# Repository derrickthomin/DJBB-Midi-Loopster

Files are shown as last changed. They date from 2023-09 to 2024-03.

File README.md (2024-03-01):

# DJBB-Midi-Loopster

The Midi Loopster is a MIDI 4x4 drum pad and midi looper based on the Raspberry Pi Pico.



Demo:          https://www.youtube.com/watch?v=YDxO62Sy1Qc&lc=UgxtoEvjVZX9zsOcOUB4AaABAg

Build Video:   https://youtu.be/qznFqSrzPKM

## Background
I created the [DJBB Arcade Button MIDI Drumpad](https://github.com/derrickthomin/djbb-midi-box) as an experiment on how to use a Raspberry Pi Pico microcontroller as a Midi controller.

It worked pretty well but I honestly don't like the super loud arcade buttons so I never really used it. I wanted an excuse to try designing my first PCB, so I decided to go for a version two of my original design except with these changes:

- Use Cherry style key switches for the buttons (quieter but still feel nice. Also smaller)

- Uses a custom PCB for max compactness and ease of build

- Switch out controls for a function button and encoder

- Firmware re-write

## Components
[DigiKey List with most parts](https://www.digikey.com/en/mylists/list/QX3GPIZNYA)

Also see BOM csv in this repo

1 x DJBB Midi Loopster PCB

1 x Raspberry Pi Pico or Pico W With Headers **djt depends on wifi stuff

1 x SSD1306 OLED Screen

5 x 10k Resistors

1 x 10 Ohm Resistor

1 x 33 Ohm Resistor

17 x Cherry MX Style key switches

1 x Rotary Encoder 

1 x 3.5mm Audio Jack

3 x 10nF Capacitors

17 x Cherry style keycaps (technically optional... but you want em)

1 x 3D printed case (optional)

1 x 3D printed screen case (optional)

1 x 4 pin female large headers for screen (optional)

4 x m2.5 screws - for screen case (optional) 

4 x m3 screws - for case (optional)

Models for printed parts here:
https://www.printables.com/model/661953-djbb-midi-loopster-3d-printed-parts

## Assembly
See the detailed Loopster Manual and Assembly Guide pdf in this repo for in depth assembly instructions.

In short:
- Solder the fn button and top left pad to the front of the board. You must do this first!! These are the top-leftmost buttons.
- Solder everything else (The pico, aux, and 2 resistors go on the back).
- Follow [Adafruit's guide](https://learn.adafruit.com/getting-started-with-raspberry-pi-pico-circuitpython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) for installing CircuitPython on your Pico

## Firmware Upload (use this to update as well)
- Delete everything from the Pico on your computer (should be showing up as a USB drive on your computer).
- Download and copy everything from "src" in this repo to the Pico

## Usage
See the detailed Loopster Manual and Assembly Guide pdf in this repo

I also sell PCBs/Kits here if ya want: https://djbajablast.etsy.com

## Changelog
_Mar 24_
- chord mode added!
- Updated logic to make it harder to accidentally change midi banks when setting velocity / encoder mode
- Scales fixed & more added. Now you can choose the root and the scale separately.

_Nov 23_
- Created new user guide + assembly manual
- Created loopster_settings.json file for easy default config
- Added performance mode config option
- Added looper feature - twist encoder CCW to remove a random loop note
- Added more scales

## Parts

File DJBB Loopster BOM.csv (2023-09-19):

 |  | DigiKey list: | https://www.digikey.com/en/mylists/list/QX3GPIZNYA
Item | Qty | Reference(s) | Value | Datasheet | Buy URL | DigiKey_Part_Number | MF | MP
1 | 1 | Brd1 | SSD1306 |  | https://www.aliexpress.us/item/3256805022051665.html?src=google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
2 | 3 | C1, C2, C3 | 10nF | https://datasheets.kyocera-avx.com/dipguard.pdf | https://www.digikey.com/en/products/detail/kyocera-avx/MD015E104MAB/1547063
3 | 1 | J1 | SJ-3524-SMT | https://www.cuidevices.com/product/resource/sj-352x-smt.pdf | https://www.digikey.com/en/products/detail/cui-devices/SJ-3524-SMT-TR/281298 | CP-3524SJCT-ND | CUI Devices | SJ-3524-SMT
4 | 5 | R1, R2, R3, R4, R5 | 10k | https://www.yageo.com/upload/media/product/productsearch/datasheet/lr/YAGEO%20CFR_datasheet_2021v0.pdf | https://www.digikey.com/en/products/detail/yageo/CFR25SJT-52-10K/13921071
5 | 1 | R6 | 33 | ~ | https://www.digikey.com/en/products/detail/stackpole-electronics-inc/CF14JT33R0/1741397
6 | 1 | R7 | 10 | ~ | https://www.digikey.com/en/products/detail/stackpole-electronics-inc/CF14JT10R0/1741276
7 | 1 | SW1 | Select Button | https://kineticlabs.com/switches/kailh/kailh-speed-switches | https://kineticlabs.com/switches/kailh/kailh-speed-switches
8 | 16 | SW2, SW3, SW4, SW5, SW6, SW7, SW8, SW9, SW10, SW11, SW12, SW13, SW14, SW15, SW16, SW17 | Cherry MX Switch | https://kineticlabs.com/switches/kailh/kailh-speed-switches | https://kineticlabs.com/switches/kailh/kailh-speed-switches
9 | 1 | SW18 | Encoder - Right | https://www.bourns.com/docs/Product-Datasheets/PEC12R.pdf | https://www.digikey.com/en/products/detail/bourns-inc/PEC12R-3220F-S0024/4699265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
10 | 1 | U1 | Pico |  | https://www.digikey.com/en/products/detail/raspberry-pi/SC0918/16608263

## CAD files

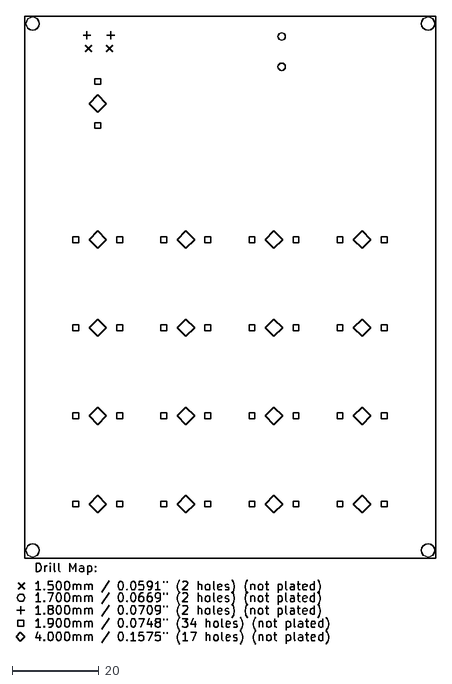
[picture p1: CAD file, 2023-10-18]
Gerbers V3/DJBB Drumpad V2 Pico-NPTH-drl_map.dxf
96.8 x 144.8

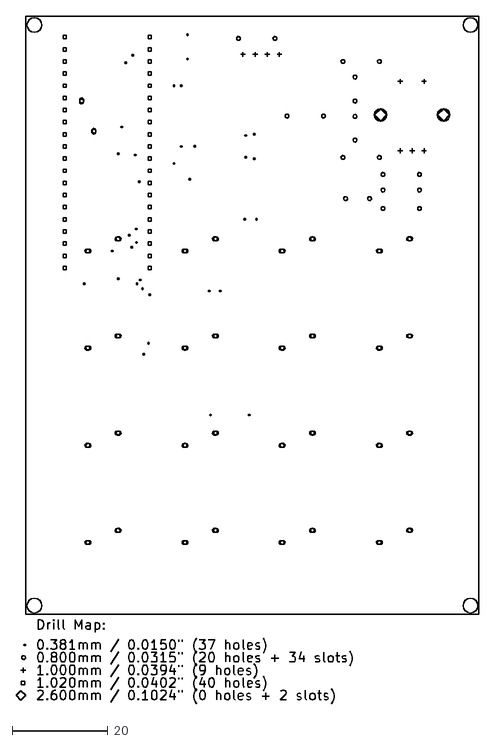
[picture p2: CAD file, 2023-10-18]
Gerbers V3/DJBB Drumpad V2 Pico-PTH-drl_map.dxf
96.8 x 143.7

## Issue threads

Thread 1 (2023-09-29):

velocity notification pops up inappropriately

derrickthomin, 2023-09-29:
it should only show if velocity is changed. too often = performance issue since it delays midi when updating screen.

derrickthomin, 2023-09-29:
I half fixed this by saying you can only change velocity on the play screen. Mostly an issue if you set varying pad velocities and then hold a lot of them.

derrickthomin, 2023-11-11:
ended up re-structuring logic and fixing this in the process.

Closed 2023-11-11.

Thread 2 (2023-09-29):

can crash when changing banks

derrickthomin, 2023-09-29:
something is busted with the bank IDX. Sometimes it goes out of range. related to using scale mode.

derrickthomin, 2023-09-29:
fixed on local device, need to update the repo then this one is fixed.

Closed 2023-09-29.

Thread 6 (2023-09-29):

Make a kill switch

derrickthomin, 2023-09-29:
I haven't needed it yet but should probs say if encoder button and fn button are held for 1s, kill all midi notes.

derrickthomin, 2024-03-01:
holding encoder button now does this. Still need to update to work with the looper tho (kill all loops as well)

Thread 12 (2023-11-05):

Update guide with TRS Midi Workaround

derrickthomin, 2023-11-05:
Multiple protocols for TRS midi exist apparently ---______---. Currently this setup doesn't work out of the box with the Korg-style trs midi. Update guide with workaround (if possible)

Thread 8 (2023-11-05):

Fix setting multiple velocities simultaneously

derrickthomin, 2023-11-05:
Right now it's wonky when you hold multiple buttons and try to set the velocity. Need to reconfigure how encoder is handled.

derrickthomin, 2023-11-08:
fixed in commit 20ccf06

Closed 2023-11-08.

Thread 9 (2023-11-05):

Looper play and rec icons don't re-appear if the screen is re-entered

derrickthomin, 2023-11-05:
need to add screen setup to check play / rec status when switching back to looper screen

derrickthomin, 2023-11-08:
fixed in commit 20ccf06

Closed 2023-11-08.

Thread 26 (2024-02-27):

Remove Button Hold Thresh for Pads

derrickthomin, 2024-02-27:
Only use for select button. it's currently too easy to switch settings when trying to set velocity on a pad, do encoder mode, etc.

derrickthomin, 2024-03-01:
Fixed. If a pad is engaged the encoder will not change the bank.

Closed 2024-03-01.

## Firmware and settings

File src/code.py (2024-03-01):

import time
import inputs
from settings import SETTINGS
from looper import setup_midi_loops, MidiLoop
import chordmaker
from menus import Menu
from debug import debug, DEBUG_MODE
from midi import (
    setup_midi,
    get_midi_note_name_text,
    send_midi_note_on,
    send_midi_note_off,
)
from display import check_show_display

# Initialize MIDI and other components
setup_midi()
setup_midi_loops()
Menu.initialize()

# Initialize time variables
polling_time_prev = time.monotonic()
if DEBUG_MODE:
    debug_time_prev = time.monotonic()

# Main loop
while True:
    timenow = time.monotonic()

    # Polling for navigation buttons
    if (timenow - polling_time_prev) > SETTINGS['NAV_BUTTONS_POLL_S']:
        inputs.check_inputs_slow()  # Update screen, button holds
        Menu.display_clear_notifications()
        check_show_display()
        if DEBUG_MODE:
            debug.check_display_debug()

    # Fast input processing
    inputs.check_inputs_fast()
    inputs.process_inputs_fast()

    # Send MIDI notes off 
    for note in inputs.new_notes_off:
        note_val, velocity = note
        if DEBUG_MODE:
            print(
                f"sending MIDI OFF val: {get_midi_note_name_text(note_val)} ({note_val}) vel: {velocity}"
            )
        send_midi_note_off(note_val)

        # Add note to current loop or chord if recording
        if MidiLoop.current_loop_obj.loop_record_state:
            MidiLoop.current_loop_obj.add_loop_note(note_val, velocity, False)
        if chordmaker.recording:
            chordmaker.current_chord_notes[chordmaker.recording_pad_idx].add_loop_note(note_val, velocity, False)

    # Send MIDI notes on
    for note in inputs.new_notes_on:
        note_val, velocity = note
        if DEBUG_MODE:
            print(
                f"sending MIDI ON val: {get_midi_note_name_text(note_val)} ({note_val}) vel: {velocity}"
            )
        send_midi_note_on(note_val, velocity)

        # Add note to current loop or chord if recording
        if MidiLoop.current_loop_obj.loop_record_state:
            MidiLoop.current_loop_obj.add_loop_note(note_val, velocity, True)
        if chordmaker.recording:
            chordmaker.current_chord_notes[chordmaker.recording_pad_idx].add_loop_note(note_val, velocity, True)

    # Handle loop notes if playing
    if MidiLoop.current_loop_obj.loop_playstate:
        new_notes = MidiLoop.current_loop_obj.get_new_notes()
        if new_notes:
            loop_notes_on, loop_notes_off = new_notes
            for note in loop_notes_on:
                send_midi_note_on(note[0], note[1])
            for note in loop_notes_off:
                send_midi_note_off(note[0])
 
    # Chord Mode loops
    for chord in chordmaker.current_chord_notes:
        if chord == "":
            continue
        new_notes = chord.get_new_notes() # chord is a loop object
        if new_notes:
            loop_notes_on, loop_notes_off = new_notes
            for note_val,velocity in loop_notes_on:
                send_midi_note_on(note_val, velocity)
                if MidiLoop.current_loop_obj.loop_record_state:
                    MidiLoop.current_loop_obj.add_loop_note(note_val, velocity, True)
            for note_val,velocity in loop_notes_off:
                send_midi_note_off(note_val) 
                if MidiLoop.current_loop_obj.loop_record_state:
                    MidiLoop.current_loop_obj.add_loop_note(note_val, velocity, False)

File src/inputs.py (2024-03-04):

from settings import SETTINGS
import board
import digitalio
import rotaryio
import midi
import chordmaker
from debug import DEBUG_MODE
from midi import (get_midi_velocity_by_idx,
                       get_midi_note_by_idx,
                       get_midi_velocity_singlenote_by_idx,
                       get_midi_note_name_text)
from menus import Menu
from time import monotonic

# PINS / SETUP
DRUMPAD_BTN_PINS = [board.GP12, board.GP13, board.GP14, board.GP15,
                    board.GP8, board.GP9, board.GP10, board.GP11, board.GP4,
                    board.GP5, board.GP6, board.GP7, board.GP0, board.GP1, board.GP2, board.GP3]

SELECT_BTN_PIN = board.GP22
ENCODER_BTN_PIN = board.GP28
ENCODER_CLK_PIN = board.GP27
ENCODER_DT_PIN = board.GP26

select_button = digitalio.DigitalInOut(SELECT_BTN_PIN)
encoder_button = digitalio.DigitalInOut(ENCODER_BTN_PIN)
encoder = rotaryio.IncrementalEncoder(ENCODER_DT_PIN, ENCODER_CLK_PIN)

select_button.direction = digitalio.Direction.INPUT
select_button.pull = digitalio.Pull.DOWN
encoder_button.direction = digitalio.Direction.INPUT
encoder_button.pull = digitalio.Pull.UP

note_buttons = []
for pin in DRUMPAD_BTN_PINS:
    note_pin = digitalio.DigitalInOut(pin)
    note_pin.direction = digitalio.Direction.INPUT
    note_pin.pull = digitalio.Pull.DOWN
    note_buttons.append(note_pin)

# TRACKING VARIABLES
encoder_pos_now = 0
encoder_delta = 0                  # Track change in encoder. Reset to 0 at end of loop (after processing)
select_button_starttime = 0
select_button_holdtime_s = 0
select_button_held = False
select_button_dbl_press = False
select_button_dbl_press_time = 0
select_button_state = False
encoder_button_state = False
encoder_button_starttime = 0
encoder_button_holdtime = 0
encoder_button_held = False
singlehit_velocity_btn_midi = None       # In this mode, 1 midi note is mapped to 16 diff velocities
any_pad_held = False
note_states = [False] * 16         # Keep track of if we are sending a midi note or not
button_states = [False] * 16       # Keep track of the state of the button - may not want to send MIDI on a press
button_press_start_times = [None] * 16
button_held = [False] * 16
new_press = [False] * 16           # Track when a new btn press.
new_release = [False] * 16         # and release
button_holdtimes_s = [0] * 16
encoder_mode_ontimes = []
new_notes_on = []               # Set when new midi note should send. Clear after sending. tuple: (note, velocity)
new_notes_off = []              # Set when a new note off message should go. int: midi note val

def update_nav_controls():
    """
    Update the navigation control states and trigger corresponding actions based on button presses and holds.
    This function manages the state and behavior of the select button and encoder button.

    Globals Used:
    - select_button_state: Indicates if the select button is currently pressed.
    - select_button_starttime: Timestamp when the select button is pressed.
    - select_button_holdtime_s: Threshold for considering the button press as a long hold.
    - select_button_held: Flag to indicate if the select button is being held down.
    - select_button_dbl_press: Flag to indicate if the select button is double-pressed.
    - select_button_dbl_press_time: Timestamp for the last double-press event.
    - encoder_button_state: Indicates if the encoder button is currently pressed.
    - encoder_button_starttime: Timestamp when the encoder button is pressed.
    - encoder_button_holdtime: Threshold for considering the encoder button press as a long hold.
    - encoder_button_held: Flag to indicate if the encoder button is being held down.

    Actions:
    - Handles single presses, double presses, and long holds for the select button.
    - Toggles the navigation mode when the encoder button is pressed.

    Usage:
    Call this function in a loop to continuously monitor and react to button presses and holds.

    Example:
    update_nav_controls()
    """
    global select_button_state
    global select_button_starttime
    global select_button_holdtime_s
    global select_button_held
    global select_button_dbl_press
    global select_button_dbl_press_time
    global encoder_button_state
    global encoder_button_starttime
    global encoder_button_holdtime
    global encoder_button_held

    # 1.2 - Check the select button
    if select_button.value and not select_button_state:

        select_button_state = True
        select_button_starttime = monotonic()
        select_button_dbl_press = False  # Reset double press flag

        # Check for a double press
        if (select_button_starttime - select_button_dbl_press_time < SETTINGS['DBL_PRESS_THRESH_S']) and not select_button_dbl_press:
            select_button_dbl_press = True
            select_button_dbl_press_time = 0
            Menu.current_menu.fn_button_dbl_press_function()
        else:
            select_button_dbl_press = False
            select_button_dbl_press_time = 0
            if DEBUG_MODE:
                print("New Sel Btn Press!!!")
            Menu.current_menu.fn_button_press_function()

    if select_button_state and (monotonic() - select_button_starttime) > SETTINGS['BUTTON_HOLD_THRESH_S'] and not select_button_held:
        select_button_held = True
        select_button_dbl_press = False  # Reset double press flag

        # Display updates
        Menu.toggle_select_button_icon(True)
        Menu.current_menu.fn_button_held_function()
        if DEBUG_MODE:
            print("Select Button Held")

    if not select_button.value and select_button_state:
        select_button_held = False
        select_button_state = False
        select_button_dbl_press_time = monotonic()  # Reference for next press to check for a double press
        select_button_starttime = 0

        # Display
        Menu.toggle_select_button_icon(False)

    # 1.3 - Check the encoder button
    if not encoder_button.value and not encoder_button_state:
        encoder_button_state = True
        Menu.toggle_nav_mode()
        encoder_button_starttime = monotonic()
        if DEBUG_MODE:
            print("New encoder Btn Press!!!")

    if encoder_button_state and (monotonic() - encoder_button_starttime) > SETTINGS['BUTTON_HOLD_THRESH_S'] and not encoder_button_held:
        # Handle long encoder button press
        encoder_button_held = True
        if DEBUG_MODE:
            print("encoder Button Held")

    if encoder_button.value and encoder_button_state:
        encoder_button_state = False
        encoder_button_starttime = 0
        encoder_button_held = False
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

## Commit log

2023-09-19 add bom
    [DJBB Loopster BOM.csv]
2023-10-18 Add Gerbers
    [DJBB Drumpad V2 Pico-B_Cu.gbl, DJBB Drumpad V2 Pico-B_Mask.gbs, DJBB Drumpad V2 Pico-B_Paste.gbp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]
2023-11-08 fix velocity issue, encoder updates
    [code.py, display.py, inputs.py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]
2024-01-20 Fix hung note issue
    [midi.py]
2024-03-06 Fix midi.py, add uf2
    [midi.py]
